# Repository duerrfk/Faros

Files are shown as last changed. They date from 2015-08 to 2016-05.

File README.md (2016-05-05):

Faros is a Bluetooth Low Energy (BLE) beacon supporting Google's open beacon 
format Eddystone [1]. As hardware platform, Faros uses Arduino and the nRF8001 
BLE chip by Nordic Semiconductors [2].

The main features are:

* Full support for all Eddystone frame types (UID, URL, TLM)
* Energy efficiency allowing for runtimes of several years
* Using popular and powerful hardware platforms: Arduino and nRF8001 BLE chip
* Simplicity of hardware: easy to build using a commodity Arduino or our
  Faros board together with the BLE module MOD-nRF8001 from Olimex [3]
* Liberal licensing: Apache License 2.0 for software, CERN Open Hardware 
  Licence v1.2 for hardware 

The following images show a self-etched Faros board and a Faros board
manufactured by a PCB manufacturer.

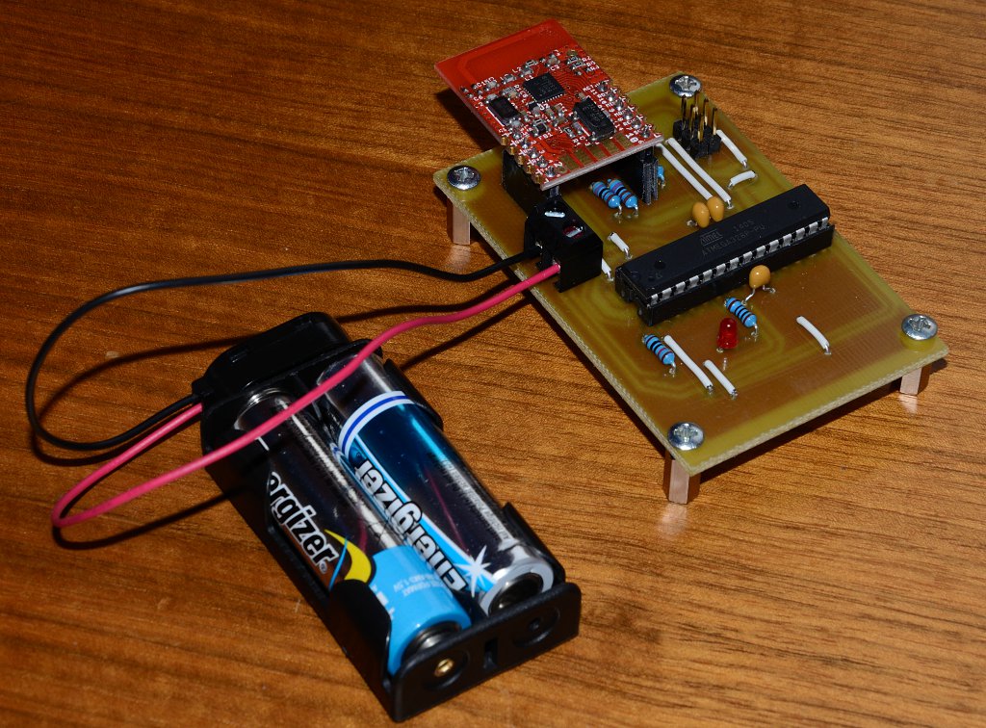
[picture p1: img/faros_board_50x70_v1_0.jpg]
Self-etched Faros board


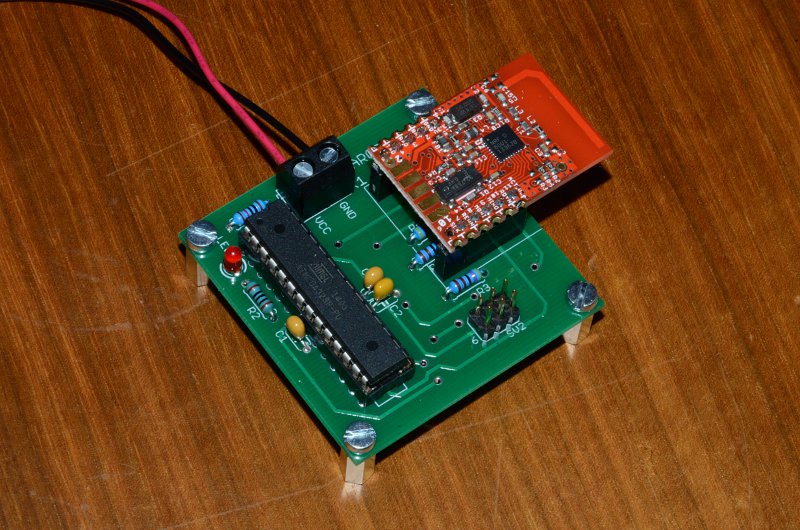
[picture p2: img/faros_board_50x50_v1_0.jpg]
Faros PCB manufactured by Seeed Studio


This project includes:

* Source code for Arduino
* Faros board schematics and board layouts

# Source Code

## Prerequisites

To compile the code, you need the Arduino IDE (tested with version 1.6.5).

Moreover, you need the Arduino BLE SDK from Nordic Semiconductors available 
from GitHub:

https://github.com/NordicSemiconductor/ble-sdk-arduino

1. Download SDK: `git clone https://github.com/NordicSemiconductor/ble-sdk-arduino.git`
2. Start the Arduino IDE (tested with v1.6.5)
3. Import the library: select `Sketch/Import library/Add` library and 
   then choose folder `libraries/BLE` from the downloaded SDK.
4. Check the availability of the library. There should be an entry `BLE`
   in menu `Sketch/Import library`.

The BLE services of nRF8001 are configured by the freely available nRFgo 
Studio tool (Windows application) [5]. This tool generates a file 
(`services.h`), which is also included in the repository. Thus, you  
only need to install this tool if you want to modify the BLE service 
description for some reason. The data of Eddystone frames is defined in the 
source code.

You also need the BLE module MOD-nRF8001 from Olimex [3]. Earlier versions 
of this module used the "C" revision of the nRF8001, which does not support
broadcasting data! So you need a module with the "D" revision of the nRF8001.
According to Olimex, all modules sold now have the "D" revision of the
nRF8001.

Since the nRF8001 module is specified for a voltage range of 1.9 V - 3.6 V, 
you should use an Arduino with suitable voltage levels. For instance, 
Arduino UNO uses 5 V, so you would have to shift levels when connecting to 
nRF8001. We tested with a 3.3 V Arduino Pro Micro and the Faros board
whose design is also included in this repository.
 
## Adapting the Source Code

If you use the Faros board or Arduino Pro Micro, you can simply
set the following definitions at the beginning of the sketch.

For the Faros board:

    #define HARDWARE_ATMEGA328P_1MHz

For Arduino Pro Micro:

    #define HARDWARE_ATMEGA32U4_8MHz

For those who are interested in the technical details: The Arduino communicates
with the nRF8001 through SPI. Beyond the standard SPI pins (MISO, MOSI, SCK, 
SS), the nRF8001 uses another select pin (called RDYN) to signal that the 
nRF8001 has events to be sent to the Arduino. Moreover, the reset pin (RST) of 
the nRF8001 has to be connected. Thus, we need 6 pins to connect the Arduino 
to the nRF8001:

1. MISO
2. MOSI
3. SCK
4. REQN/SS
5. RDYN
7. RST

For the standard SPI pins, select the usual pins depending on your Arduino.
RDYN should be assigned to a pin with a hardware interrupt. We use this 
interrupt to wake up the Arduino from power-down mode when the nRF8001 wants
to send an event to the Arduino.

For the Arduino Pro Micro, we used the following pins according to the
Arduino numbering scheme:

* MISO = 14
* MOSI = 16
* SCK = 15
* REQN/SS = 7
* RDYN = 3 -> INT0
* RST = 4

For the Faros board based on ATmega328P, we used the following pins (Arduino 
numbering scheme; ATmega names are given in brackets):

* MISO = 12 (PB4)
* MOSI = 11 (PB3)
* SCK = 13 (PB5)
* REQN/SS = 10 (PB2)
* RDYN = 2 (PD2) -> INT0
* RST = 3 (PD3)

Moreover, nRF8001 supports a maximum SPI clock frequency of 3 MHz. To adjust the
SPI clock frequency, set the definition SPI_CLOCK_DIV according to your 
platform. For instance, the Arduino Pro Micro is running at 8 MHz, so we need 
to divide it by 4 (SPI_CLOCK_DIV4) to get 2 MHz. The Faros board uses an 
ATmega328P at 1 MHz, so theoretically we could divide by 1. However, the 
smallest divider available for ATmega is 2 (SPI_CLOCK_DIV2), so we will run at 
500 kHz SPI clock.

Finally, you need to set your specific data to be broadcasted by the beacon.
Eddystone supports the following data:

* UID frames:
    * beacon ID consisting of namespace id and instance id
    * TX power level
* URL frame: 
    * short URL 
    * TX power level
* TLM frame: 
    * battery level
    * temperature
    * uptime
    * number of broadcasted frames since boot

You need to set the data for UID and URL frames through variables at the 
beginning of the sketch. The data for TLD frames is detected automatically 
(nRF8001 features a temperature sensor and voltage sensor).

Moreover, you can select whether you want to send UID and/or URL frames 
and/or TLM frames by setting the variables `is_enabled_uid`, `is_enabled_url`, 
and `is_enabled_tlm`, respectively. The beacon will cycle through all 
enabled frames, so it can send UID frames, URL frames, and TLM frames 
(sequentially).

# Hardware: The Faros Board

If you just want to experiment, you can simply use a commodity Arduino 
running at 3.3 V like the Arduino Pro Micro. Just directly connect the pins
of the Arduino Pro Micro and the BLE module like this:

* MISO = 14
* MOSI = 16
* SCK = 15
* REQN/SS = 7
* RDYN = 3 -> INT0
* RST = 4

However, if you want to deploy beacons in the field, two requirements become 
essential:

* Energy efficiency: the beacon must run from battery for several years 
* Cost: if you want to deploy many beacons, a commodity Arduino board
  is too expensive

The Faros board tries to fulfill these requirements plus one more: keep
things as simple as possible so virtually everyone can build a Faros
beacon.

The Faros board uses an ATmega328P together with the BLE module MOD-nRF8001 
from Olimex [3] based on the nRF8001 chip from Nordic Semiconductors. We 
selected the nRF8001 for several reasons:

* Easy to connect to Arduino through SPI
* Open Arduino SDK [4]
* Includes temperature sensor (required for TLM frames)
* Includes voltage sensor (required for TLM frames)

The BLE module MOD-nRF8001 from Olimex provides a ready-to-use solution to use
the nRF8001 together with the Arduino.

The Faros board is kept as simple as possible (through-hole design, no SMD 
components). It comes in two variants: (1) a single-sided 50 mm x 70 mm layout 
that is well-suited for self-etching (a PDF of the layout can be found in 
folder `pcb`); (2) a double-sided 50 mm x 50 mm layout that can be sent to a 
PCB manufacturer (the Gerber files can be found in folder `gerber`). For both 
variants, the ATmega is programmed using ISP, so no USB is required which 
again saves cost and energy. Moreover, we use the ATmega's internal RC 
oscillator, so no external crystal is required. 

Here is the bill of material for the Faros board:

* C1, C2, C3: 100 nF (ceramic capacitor, X7R, 5.08 pitch)
* LED1: 3 mm
* R1: 10 k Ohm
* R2: 100 Ohm
* R3, R4, R5: 4.7 k Ohm
* IC1: ATmega328P-PU
* MOD1: Olimex MOD-nRF8001
* SV1: 3x2 pin header (2.54 pitch)
* X1: screw terminal (5.08 pitch)

## Programming the Faros Board

The Faros board is programmed via ISP. The 6 pin ISP6 connector has the usual 
layout:

    MISO <-- 1 2 --> VCC
     SCK <-- 3 4 --> MOSI
     RST <-- 5 6 --> GND

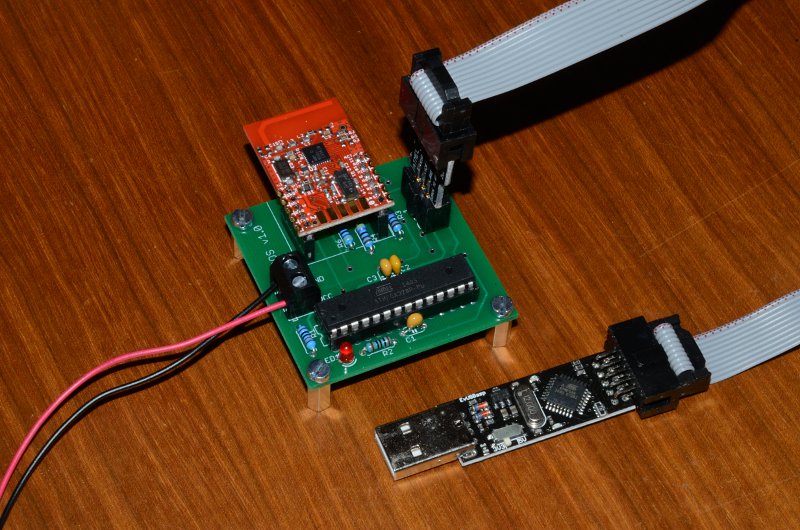
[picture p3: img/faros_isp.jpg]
Faros board connected to ISP


You can leave the BLE module connected while programming the ATmega (the 
4.7 k resistors shield the SPI pins of the nRF8001 during programming). However,
you should use a 3.3 V programmer since the maximum voltage of the nRF8001
is 3.6 V.

To preprare the ATmega328P, program the following fuses (note that "0" means 
that the fuse is programmed):

* CKSEL = 0010: use internal 8 MHz RC oscillator
* CKDIV8 = 0: 1 MHz system clock (dividing the 8 MHz internal clock by 8)
* SPIEN = 0: enable serial programming
* BODLEVEL = 110: brown-out detection set to 1.8 V
* SUT = 00: lowest possible startup time (6 CK from power-down; since we use
  BOD, we do not need additional waiting time for the power source to come up)
    
Using avrdude, the command looks like this (note: under Linux you might need
to execute this command as root depending on your programmer):

    $> avrdude -c usbasp -p m328p -U lfuse:w:0x42:m -U hfuse:w:0xd9:m -U efuse:w:0x06:m

Then, we compile and write the program to the ATmega. Before compiling the 
program, make sure you have adapted the pins (see above), SPI clock divider 
(see above), and to generate code for an ATmega at 1 MHz. In the repository, 
you will find a suitable board definition for the Arduino IDE (see folder 
`board_definition`). Copy the directory `faros-atmega` into the folder 
`hardware` in your Arduino sketchbook. Then you should find and select the 
board  called `Faros ATMega 328P @ 1 MHz` under the menu item `Tools/Board`. 

Compiling generates a hex file that we need to program the ATmega. This hex 
file is a little bit hidden in the temporary build directory of the Arduino
IDE. If you use Linux  and Arduino IDE 1.6, have a look at the `/tmp` 
directory. After hitting the  compile button in the Arduino IDE, search for the
latest hex file called  `faros.cpp.hex` in a temporary directory named 
`/tmp/build...`. If you have found the hex file, you can write it using avrdude
(again, you might need root right):

    $> avrdude -p m328p -c usbasp -v -U flash:w:faros.cpp.hex
 
## Saving Energy

The basic method to save energy is to minimize the duty cycle. Therefore,
we put the ATmega into power-down mode (deepest power-saving mode) as long as
possible, and only wake it up, when some work has to be done. This can either
be an event from the nRF8001 module , which triggers a hardware interrupt on
the RDYN pin. Or it can be a timer event from the watch dog timer (which
keeps running in power-down mode in contrast to the other timers). By switching
of the ADC and disabling brown-out detecting while sleeping (only possible
with the ATmega328P, not with the ATmega328), the ATmega328P only consumes 
a few uA (actually, the "P" in 328P means "pico-power"). 

Another important design choice is the type of battery. The nRF8001 
can run down to 1.9 V; the ATmega down to 1.8 V at frequencies <= 4 MHz. The 
maximum voltage for the nRF8001 is 3.6 V. Thus, one good option is to use two 
AA or AAA size alkaline batteries. They are cheap. They provide > 1800 mAh, 
which should suffice for several years of runtime. They are discharged at about 
1.0 V (then the voltage drops rapidly), which fits nicely our desired voltage 
range of 1.9 - 3.0 V. And at runtimes of several years, no re-charging is
required (you rather replace the device than changing the batteries). Of 
course, you can also try out other options like coin cells (e.g., one 
CR 2450 @ 3.0 V, 560 mAh), or one battery (1.5 V) plus a step-up converter 
(which wastes maybe more than 20 % energy for conversion and is probably more
expensive than a second AA or AAA battery).

The board also has a 3 mm low-current LED, which can be switched on by digital 
pin 4 of the Arduino. With a resistor of 100 Ohm, it draws 10 mA at 3 V, which 
is a lot if we target runtimes of several years! So if you aim at maximum 
battery lifetime, only send short pulses in long intervals (e.g., one 100 ms 
pulse every 30 s amounts to about 33 uA average current), or even better: rely 
on TLM frames.

# Testing

In order to test that your beacon works, you need a client, e.g., a mobile
phone or tablet with BLE and an application that understands Eddystone
beacons. There are (at least) two nice apps for Android that show all the
details of the three types of Eddystone frames:

* nRFMaster Control Panel by Nordic Semiconductors [6]
* Eddystone Validator by Google (requires Android 5 aka. Lollipop) [7]

Faros is cycling through all frame types (if you have enabled all of them)
and switches to a new frame type every second. So after about 3 seconds you 
should see the data of all three frame types (most interesting is maybe
the TLM type since its data changes dynamically).

# Licensing

Faros uses two licenses for open hardware and software, respectively:

* The software (source code) is licensed under the Apache License 2.0 [8]
* The hardware (schematic diagrams, circuit board layouts, hardware
  documentation) is licensed under the CERN Open Hardware Licence v1.2 [9]

Both licenses are also included in the repository.

# References

* [1] https://developers.google.com/beacons/
* [2] https://www.nordicsemi.com/eng/Products/Bluetooth-Smart-Bluetooth-low-energy/nRF8001 
* [3] https://www.olimex.com/Products/Modules/RF/MOD-nRF8001/
* [4] https://github.com/NordicSemiconductor/ble-sdk-arduino
* [5] https://www.nordicsemi.com/chi/node_176/2.4GHz-RF/nRFgo-Studio
* [6] https://www.nordicsemi.com/eng/Products/nRFready-Demo-Apps/nRF-Master-Control-Panel-application
* [7] https://github.com/google/eddystone
* [8] http://www.apache.org/licenses/LICENSE-2.0
* [9] http://www.ohwr.org/attachments/2388/cern_ohl_v_1_2.txt

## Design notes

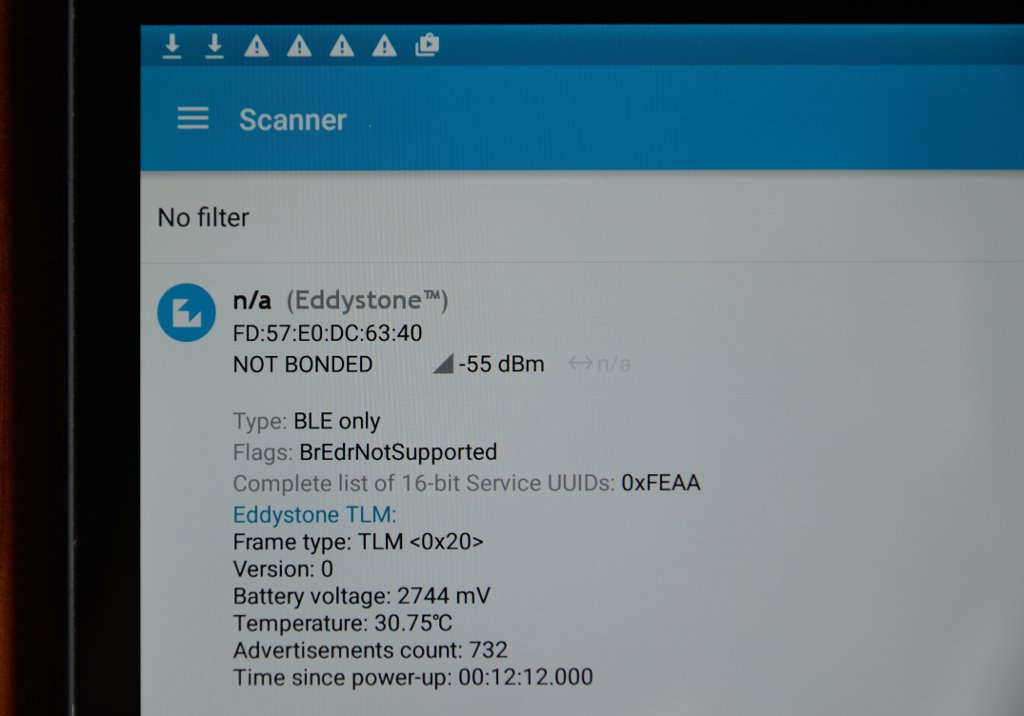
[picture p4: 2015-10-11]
img/nrfmaster03.jpg

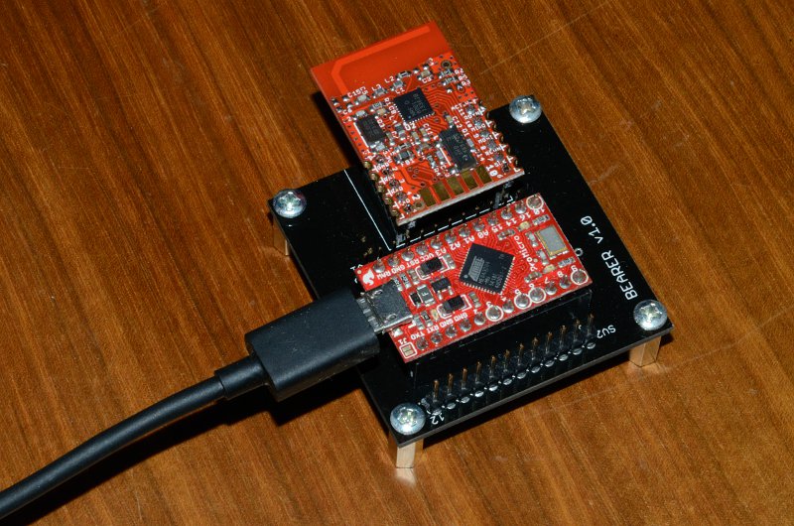
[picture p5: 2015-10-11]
img/faros_arduinopromicro.jpg

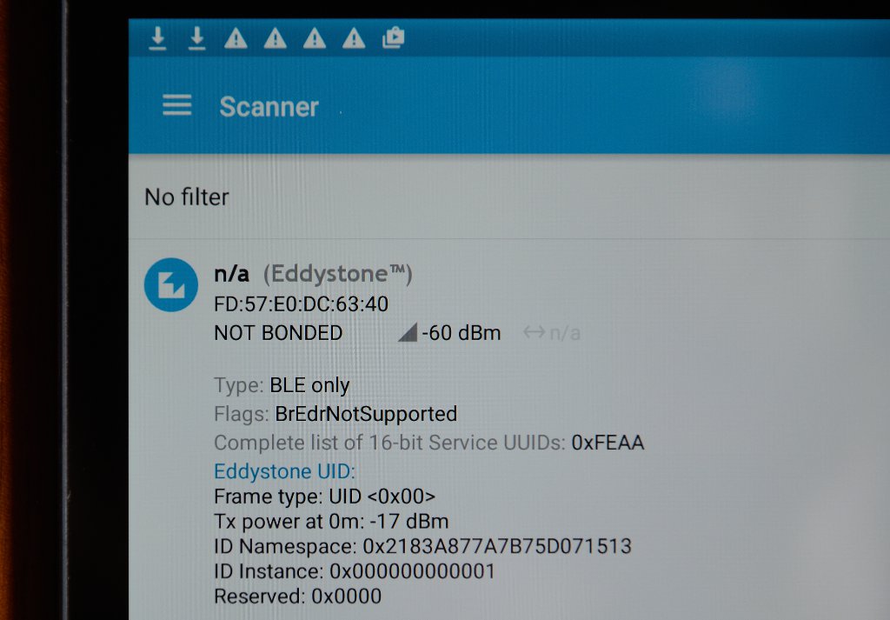
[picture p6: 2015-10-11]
img/nrfmaster01.jpg

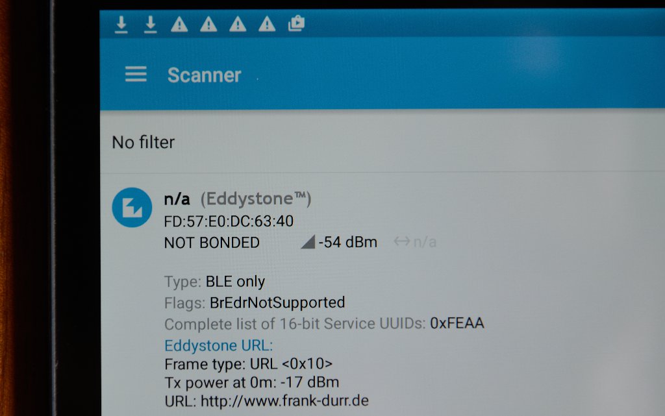
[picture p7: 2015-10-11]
img/nrfmaster02.jpg

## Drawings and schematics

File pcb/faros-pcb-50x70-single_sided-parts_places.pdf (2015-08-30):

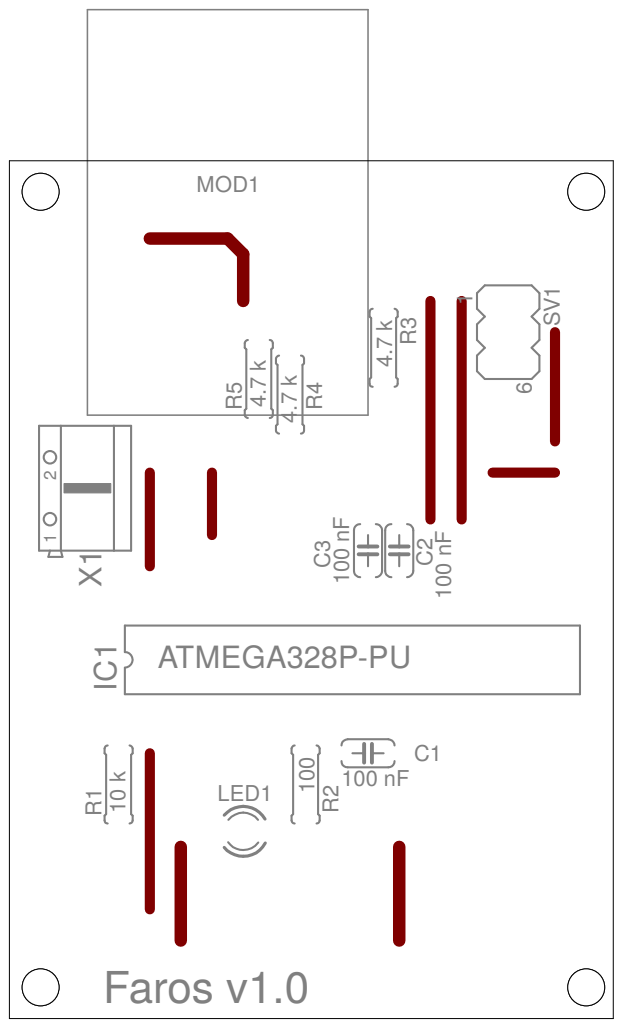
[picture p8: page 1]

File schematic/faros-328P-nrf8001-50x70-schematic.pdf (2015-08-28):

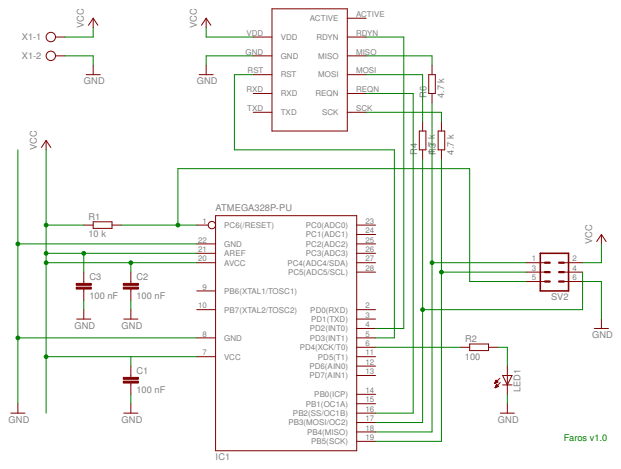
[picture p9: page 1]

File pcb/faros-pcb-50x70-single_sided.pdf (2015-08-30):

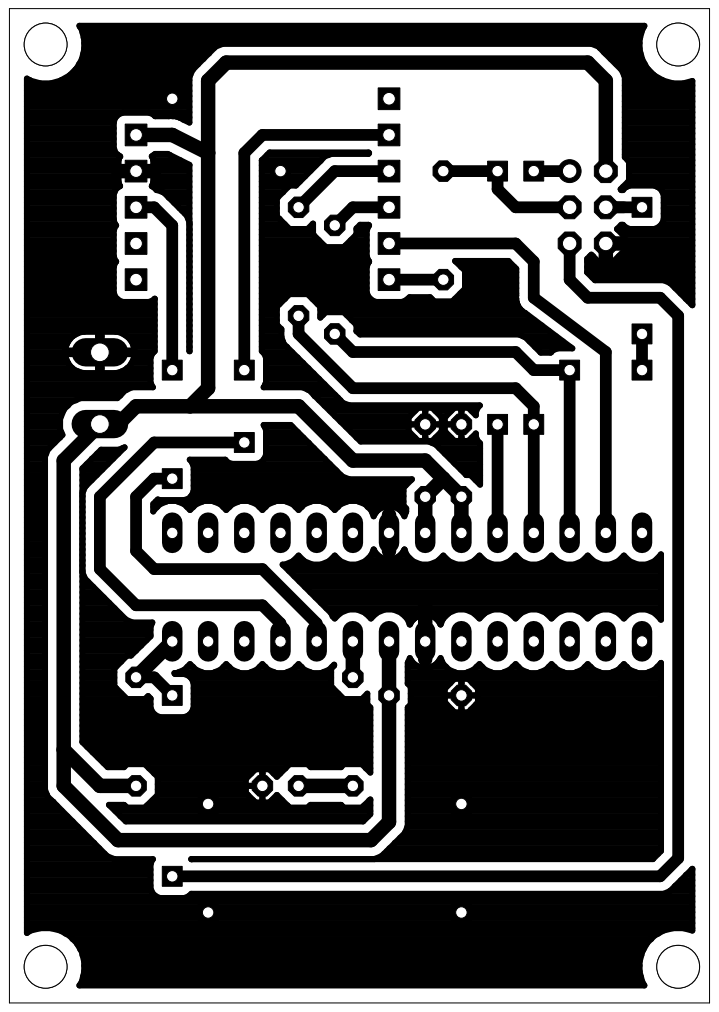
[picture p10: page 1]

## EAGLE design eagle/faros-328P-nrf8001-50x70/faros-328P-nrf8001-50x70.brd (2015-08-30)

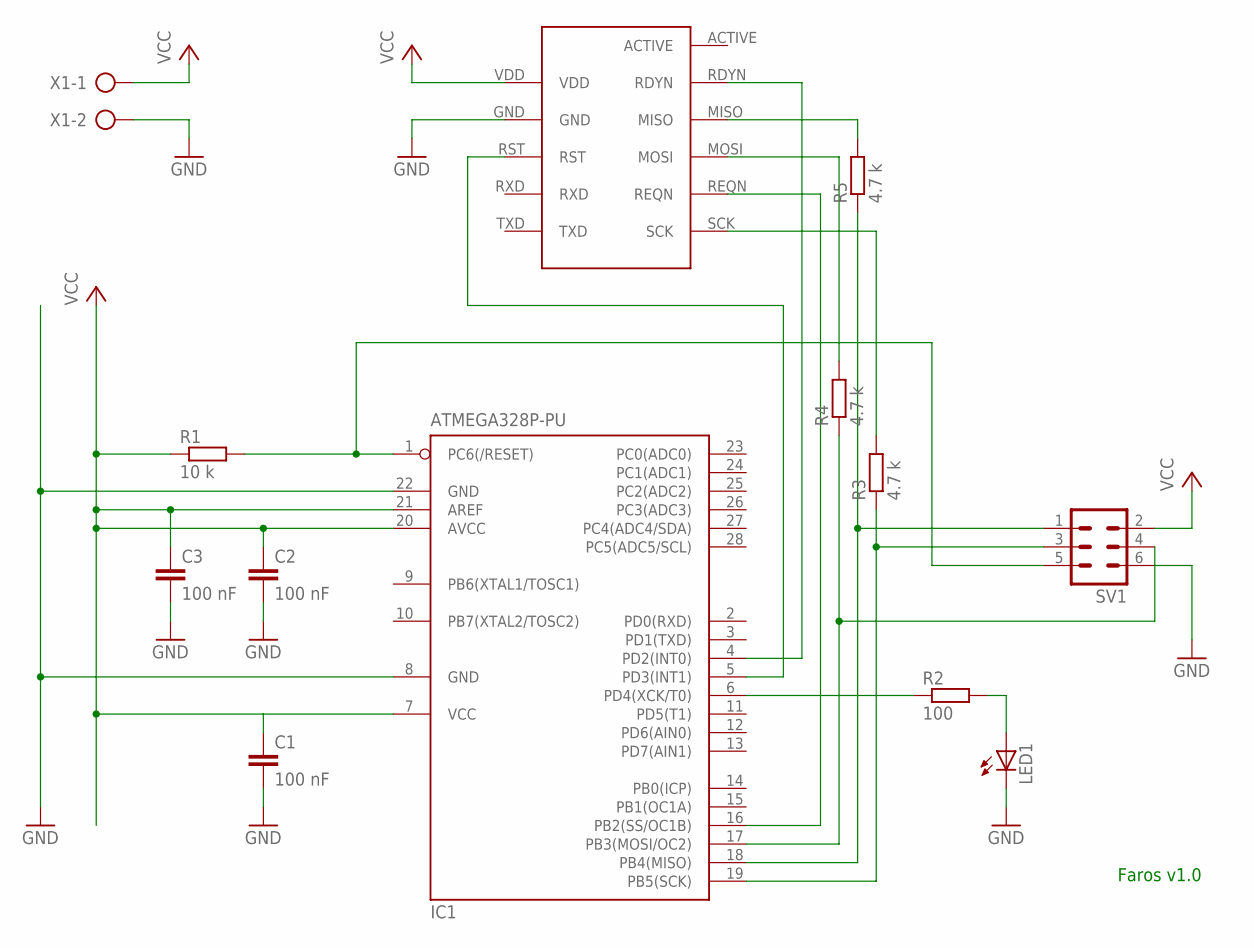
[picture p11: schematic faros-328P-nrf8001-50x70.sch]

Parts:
C1, C2, C3: 100 nF; C050-024X044
IC1: ATMEGA328P-PU; DIL28-3
LED1: LED3MM
MOD1: MOD-NRF8001MOD-NRF8001; MOD-NRF8001
R1: 10 k; 0207/7
R2: 100; 0207/7
R3, R4, R5: 4.7 k; 0207/7
SV1: MA03-2
X1: AK500/2

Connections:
GND: C1.2, C2.2, C3.2, IC1.8 (GND), IC1.22 (GND), LED1.K (C), MOD1.GND, SV1.6, X1.2
unnamed: IC1.4 (PD2(INT0)), MOD1.RDYN
unnamed: IC1.19 (PB5(SCK)), R3.1, SV1.3
unnamed: IC1.1 (PC6(/RESET)), R1.2, SV1.5
unnamed: MOD1.MOSI, R4.2
unnamed: MOD1.MISO, R5.2
unnamed: IC1.5 (PD3(INT1)), MOD1.RST
unnamed: LED1.A, R2.2
unnamed: IC1.6 (PD4(XCK/T0)), R2.1
unnamed: MOD1.SCK, R3.2
unnamed: IC1.16 (PB2(SS/OC1B)), MOD1.REQN
unnamed: IC1.18 (PB4(MISO)), R5.1, SV1.1
unnamed: IC1.17 (PB3(MOSI/OC2)), R4.1, SV1.4
VCC: C1.1, C2.1, C3.1, IC1.7 (VCC), IC1.20 (AVCC), IC1.21 (AREF), MOD1.VDD, R1.1, SV1.2, X1.1

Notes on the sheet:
Faros v1.0

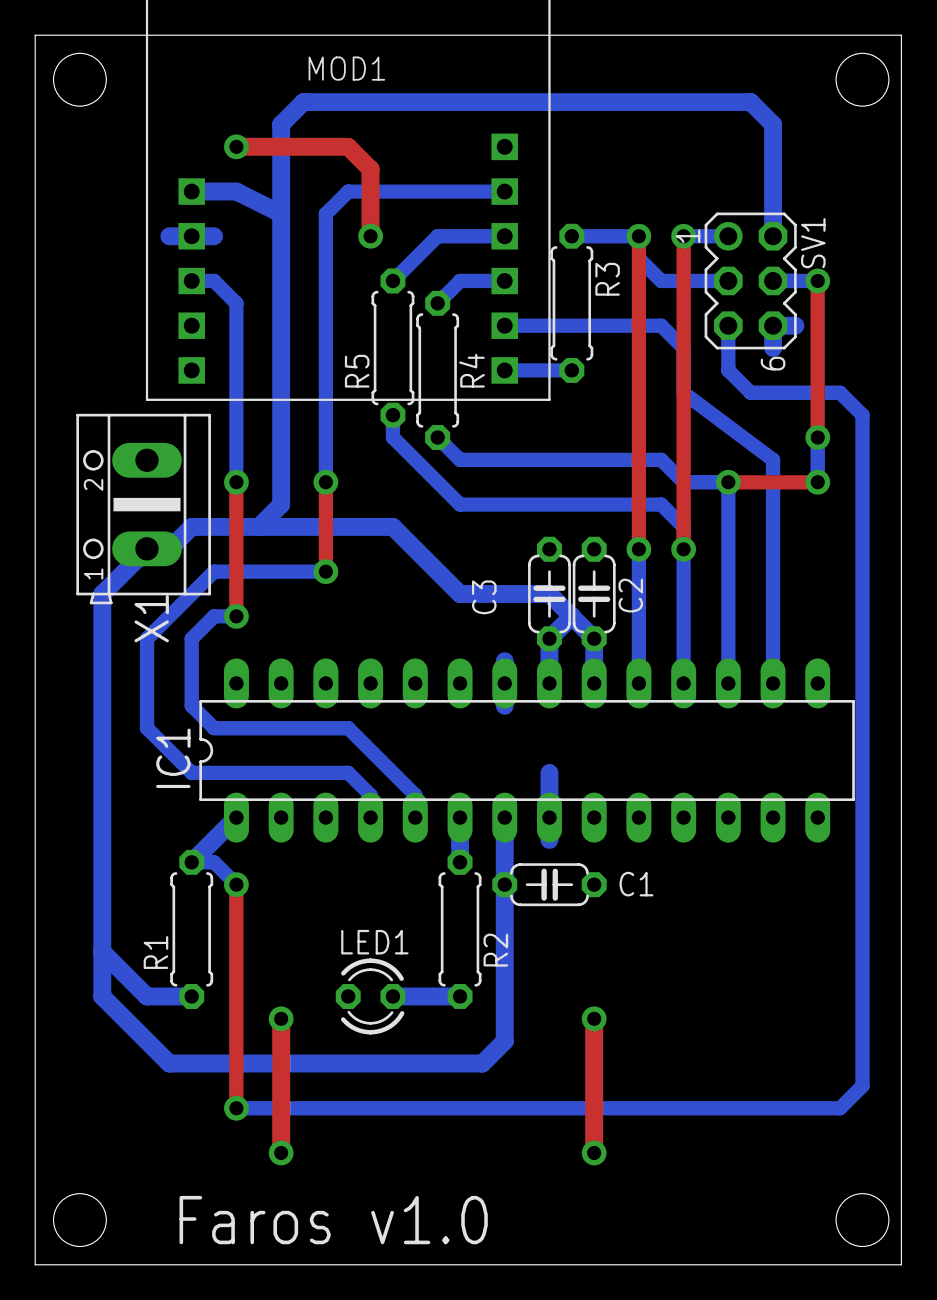
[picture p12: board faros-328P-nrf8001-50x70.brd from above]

Board: 2 copper layers, 49.2 x 69.8 mm, 13 parts (0 on the bottom side), 14 nets.

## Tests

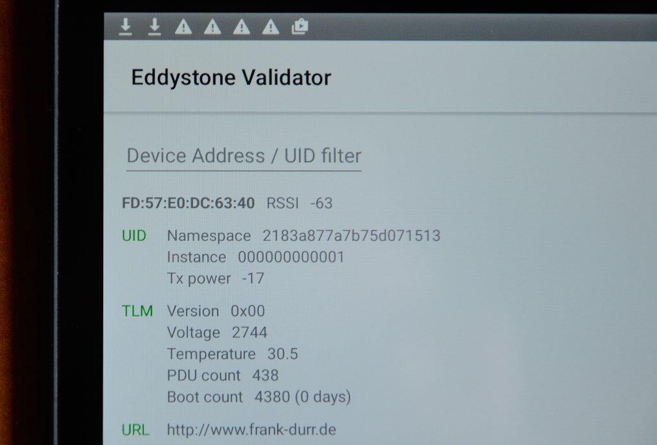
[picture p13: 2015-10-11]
img/validator.jpg

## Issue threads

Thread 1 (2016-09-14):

Will this work with nrf24l01?

Milap7, 2016-09-14:

duerrfk, 2016-09-14:
No, you need a board with [nRF8001](https://www.nordicsemi.com/eng/Products/Bluetooth-low-energy/nRF8001), such as the [MOD-nRF8001](https://www.olimex.com/Products/Modules/RF/MOD-nRF8001/) (the provided PCB layout is for this board) or [Bluefruit LE](https://www.adafruit.com/product/1697).

Closed 2016-09-14.

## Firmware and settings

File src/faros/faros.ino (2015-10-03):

/**
 * This file is part of Faros.
 * 
 * Copyright 2015 Frank Duerr
 *
 * Licensed under the Apache License, Version 2.0 (the "License");
 * you may not use this file except in compliance with the License.
 * You may obtain a copy of the License at
 * 
 * http://www.apache.org/licenses/LICENSE-2.0
 * 
 * Unless required by applicable law or agreed to in writing, software
 * distributed under the License is distributed on an "AS IS" BASIS,
 * WITHOUT WARRANTIES OR CONDITIONS OF ANY KIND, either express or implied.
 * See the License for the specific language governing permissions and
 * limitations under the License.
 */
 
// Need to include EEPROM.h here although it is not reference from this file
// (at least Arduino 1.5.8 IDE fails to include it automatically). 
#include <EEPROM.h>
#include <SPI.h>
#include <avr/wdt.h>
#include <avr/sleep.h>
#include <lib_aci.h>
#include <aci_setup.h>
#include "services.h"
#include "url_schemes.h"
#include "commands.h"

//// Define your hardware platform to set pin mappings, etc. 
// The following definition is suitable for the Faros board. 
//#define HARDWARE_ATMEGA328P_1MHz
// The following definition is suitable for Arduino Pro Micro.
#define HARDWARE_ATMEGA32U4_8MHz

// Putting the MCU into power-down mode is essential to save 
// energy and to achieve runtimes of several years. However, 
// be careful if you use an Arduino flashed via serial port
// like Arduino Pro Micro. If the serial port is not 
// discovered by your PC until the device falls asleep, you 
// might not be able to flash it anymore, via serial port. 
// To recover, you have two options: 
//
// 1. Connect a cable between PIN_RDYN and GND of the Arduino. 
//    This will prevent the the activation of power-down 
//    mode since INT0 is constantly active (the device thinks,
//    that the nRF8001 wants to send events).
// 2. Flash via ISP
//
// Since the Faros board is flashed via ISP anyway, it is
// save to use this setting with the Faros board.
#ifdef HARDWARE_ATMEGA328P_1MHz
#define DO_SLEEP
#endif

// Disabling brown-out detecting while sleeping saves about 25 uA.
// Not all MCUs support this. ATmega328P used by the Faros board 
// does. ATmega32U4 used by Arduino Pro Micro doesn't.
#ifdef HARDWARE_ATMEGA328P_1MHz
#define DISABLE_BOD_WHILE_SLEEPING
#endif

// 8.8 fixed point arithmetic
#define FIXED_8_8_FBITS 8
#define FIXED_8_8_ONE (1<<FIXED_8_8_FBITS)
#define FIXED_8_8_FROM_FLOAT(x) ((int16_t) ((x)*FIXED_8_8_ONE))

//// Arduino pins connected to nRF8001.
#ifdef HARDWARE_ATMEGA32U4_8MHz
// The following values are valid for Arduino Pro Micro. 
#define PIN_MOSI 16
#define PIN_MISO 14
#define PIN_SCK 15
// nRF8001 uses two "slave select" pins, one from Arduino (master) to nRF8001
// (slave) called REQN, and one from slave to master called RDYN for signaling 
// events from nRF8001 to Arduino. For RDYN select a pin with attached 
// hardware interrupt to enable wake-up from sleep mode. 
#define PIN_REQN 7
#define PIN_RDYN 3  
#define PIN_RST 4

// We use this interrupt to react to RDYN events. nRF8001 pulls
// RDYN low, when it has some data to send to the MCU.
// pin 3 = RDYN is linked to INT0 on Arduino Pro Micro.
#define RDYN_INTR_NO 0

// nRF8001 supports max. 3 MHz SPI clock frequency.
// Arduino Pro Micro runs at 8 MHz. By dividing by 4, we
// set the SPI clock frequency to 2 MHz.    
#define SPI_CLOCK_DIV SPI_CLOCK_DIV4
#endif

#ifdef HARDWARE_ATMEGA328P_1MHz
// The following values are valid for the Faros board. 
#define PIN_MOSI 11
#define PIN_MISO 12
#define PIN_SCK 13
// nRF8001 uses two "slave select" pins, one from Arduino (master) to nRF8001
// (slave) called REQN, and one from slave to master called RDYN for signaling 
// events from nRF8001 to Arduino. For RDYN select a pin with attached 
// hardware interrupt to enable wake-up from sleep mode. 
#define PIN_REQN 10
#define PIN_RDYN 2  
#define PIN_RST 3

// We use this interrupt to react to RDYN events. nRF8001 pulls
// RDYN low, when it has some data to send to the MCU.
// pin 2 = RDYN is linked to INT0 on the Faros board.
#define RDYN_INTR_NO 0

// nRF8001 supports max. 3 MHz SPI clock frequency.
// The Faros board runs at 1 MHz. Two is the smallest clock
// divider that we can set:    
#define SPI_CLOCK_DIV SPI_CLOCK_DIV2
#endif

// Advertisement interval in 0.625 ms, min 0x0020 (20 ms), max 0x4000 (10.240 s). 
// 1600 -> 1 s
#define ADV_INTERVAL 1600

// Maximum sizes of the different Eddystone frames 
#define EDDYSTONE_UID_DATA_SIZE 20
#define EDDYSTONE_URL_DATA_SIZE 20
#define EDDYSTONE_TLM_DATA_SIZE 14

//// nRF8001 data structures
#ifdef SERVICES_PIPE_TYPE_MAPPING_CONTENT
    services_pipe_type_mapping_t services_pipe_type_mapping[NUMBER_OF_PIPES] = SERVICES_PIPE_TYPE_MAPPING_CONTENT;
#else
    #define NUMBER_OF_PIPES 0
    services_pipe_type_mapping_t *services_pipe_type_mapping = NULL;
#endif

// Store the setup for the nRF8001 in the flash of the AVR (PROGMEM) to save on RAM
const hal_aci_data_t setup_msgs[NB_SETUP_MESSAGES] PROGMEM = SETUP_MESSAGES_CONTENT;

// Selection of Eddystone frame types that should be sent
const boolean is_enabled_uid = true;
const boolean is_enabled_url = true;
const boolean is_enabled_tlm = true;

//// Definition of data for the different Eddystone frame types.
// Note that multi-byte Eddystone data is in Big-Endian format.
// Frame type ids
const uint8_t eddystone_frame_type_uid = 0x00;
const uint8_t eddystone_frame_type_url = 0x10;
const uint8_t eddystone_frame_type_tlm = 0x20;

// 10 byte namespace id. Google suggests different methods to create this:
// - Truncated hash: first 10 bytes of your SHA1 hash of your FQDN.
// - Elided Version 4 UUID: version 4 UUID with bytes 5 - 10 (inclusive) removed 
const uint8_t eddystone_namespace_id[] = {0x21, 0x83, 0xa8, 0x77, 0xa7, 0xb7, 0x5d, 0x07, 0x15, 0x13};
// 6 byte instance id (any scheme you like).
const uint8_t eddystone_instance_id[] = {0x00, 0x00, 0x00, 0x00, 0x00, 0x01};
// TX power in dBm, calibrated at 0 m distance.
// Range: -100 dBm to +20 dBm; resolution: 1 dBm.
// Can be found out empirically by measuring the signal strength at 1 m.
// distance and adding 41 dBm.
const int8_t eddystone_txpwr = -17;
// Scheme of the encoded URL.
const url_schemes eddystone_url_scheme = http_www_dot;
// Encoded URL (max. 17 bytes)
// The following bytes expand to a sequence of characters:
// 0x00  .com/
// 0x01  .org/
// 0x02  .edu/
// 0x03  .net/
// 0x04  .info/
// 0x05  .biz/
// 0x06  .gov/
// 0x07  .com
// 0x08  .org
// 0x09  .edu
// 0x0a  .net
// 0x0b  .info
// 0x0c  .biz
// 0x0d  .gov
// 14..32  0x0e..0x20  Reserved for Future Use
// 127..255  0x7F..0xFF  Reserved for Future Use
// The following example encodes the URL frank-duerr.de
// ("http://www." is added by the schema definition)
const uint8_t eddystone_enc_url[] = {0x66, 0x72, 0x61, 0x6e, 0x6b, 0x2d, 0x64, 0x75, 0x72, 0x72, 0x2e, 0x64, 0x65};
const unsigned int eddystone_enc_url_size = sizeof(eddystone_enc_url);
// TLM version
const uint8_t eddystone_tlm_version = 0x00;

// Complete Eddystone UID frame:
// - 1 byte frame type (0x00 for UID frame)
// - 1 byte TX power
// - 10 byte namespace id
// - 6 byte instance id
// - 2 bytes reserved (must be set to 0x00 0x00)
uint8_t eddystone_uid_data[EDDYSTONE_UID_DATA_SIZE];
unsigned int eddystone_uid_data_size;
 
// Complete Eddystone URL frame:
// - 1 byte frame type (0x10 for UID frame)
// - 1 byte TX power
// - 1 byte URL scheme
// - 0-17 bytes encoded URL
uint8_t eddystone_url_data[EDDYSTONE_URL_DATA_SIZE];
unsigned int eddystone_url_data_size;

// Complete Eddystone TLM frame:
// - 1 byte frame type (0x20 for TLM frame)
// - 1 byte TLM version (currently 0x00)
// - 2 byte battery level in millivolt. 
// - 2 byte temperature (degree Celsius; signed 8.8 fixed point notation)
// - 4 bytes adv. PDU count (total count of advertisement frames of 
//   all types emitted by the beacon since (re-)boot)
// - 4 bytes time since (re-)boot (0.1 sec resolution)
uint8_t eddystone_tlm_data[EDDYSTONE_TLM_DATA_SIZE];
unsigned int eddystone_tlm_data_size;

// Temperature [degree Celsius]
float temperature = 12.34;
// Battery level [volt]
float voltage = 1.23;
// Total number of advertisement frames sent since re-boot
uint32_t adv_pdu_cnt = 0;
// Uptime in tens of seconds
uint32_t uptime = 0;

struct aci_state_t aci_state;
hal_aci_evt_t  aci_data;
hal_aci_data_t aci_cmd;

volatile boolean ble_ready = false;
volatile boolean timer_fired = false;
boolean is_broadcasting = false;

// Eddystone frame types are sent round robin. 
// Variable next_frame_type tells, which frame type to send next.
enum frame_types {uid, url, tlm};
enum frame_types next_frame_type;

// nRF8001 can only process one system command at a time.
// After sending a request, we need to wait for the response
// before sending the next command. In order to simplify implementation,
// we queue pending commands in a command queue. Whenever a response
// is received, the next command is taken out of the queue and sent
// to nRF8001. The command queue is implemented as a ring buffer.
#define CMD_QUEUE_SIZE 16
#define CMD_QUEUE_SIZE_MOD_MASK 0x0f 
enum commands cmd_queue[CMD_QUEUE_SIZE];
unsigned int cmd_queue_head = 0;
unsigned int cmd_queue_tail = 0;
unsigned int cmd_queue_free = CMD_QUEUE_SIZE;
boolean cmd_queue_pending = false;

/**
 * Called after a fatal error happened. 
 */
void die()
{  
    // Enable watchdog system reset mode to reboot system with next
    // watch dog event. 
    //WDTCSR |= _BV(WDE);
    
    // Go into endless loop. User will notice error through TLM frames
    // (either missing or counters don't increase anymore).
    while (true);
}

/**
 * Enqueue a command into the command queue. 
 * 
 * @param command the command to be enqueued
 * 
 * @returns true if the command fits into the queue; false if
 *          there is no space in the queue anymore.
 */
boolean cmd_queue_enqueue(enum commands command)
{
    if (cmd_queue_free == 0)
        return false;

    cmd_queue[cmd_queue_head] = command;
    cmd_queue_head++;
    cmd_queue_head &= CMD_QUEUE_SIZE_MOD_MASK;
    cmd_queue_free--;
    
    // Try to send command
    cmd_queue_send_cmd();

    return true;
}

/**
 * If no other command is pending and there is at least
 * one queued command, send next command to nRF8001.
 */
void cmd_queue_send_cmd() 
{
    // Cannot send a command if either a command is pending 
    // or queue is empty
    if (cmd_queue_pending || cmd_queue_free == CMD_QUEUE_SIZE)
        return;
        
    enum commands cmd = cmd_queue[cmd_queue_tail];
    switch (cmd) {
    case get_temperature :
        lib_aci_get_temperature();
        break;
    case get_battery_level :
        lib_aci_get_battery_level();
        break;
    case send_uid_frame :
        lib_aci_set_local_data(&aci_state, 
            PIPE_EDDYSTONE_EDDYSTONEDATA_BROADCAST,
            eddystone_uid_data, EDDYSTONE_UID_DATA_SIZE);
        break;
    case send_url_frame :
        lib_aci_set_local_data(&aci_state, 
            PIPE_EDDYSTONE_EDDYSTONEDATA_BROADCAST,
            eddystone_url_data, eddystone_url_data_size);
        break;
    case send_tlm_frame :
        eddystone_tlm_data_size = setup_eddystone_TLM_frame(eddystone_tlm_data, 
            eddystone_tlm_version, voltage, temperature, adv_pdu_cnt, uptime);
        lib_aci_set_local_data(&aci_state, 
            PIPE_EDDYSTONE_EDDYSTONEDATA_BROADCAST,
            eddystone_tlm_data, eddystone_tlm_data_size);
        break;
    case open_adv_pipe :
        lib_aci_open_adv_pipe(PIPE_EDDYSTONE_EDDYSTONEDATA_BROADCAST);
        break;
    case start_broadcasting :
        // Start advertising in non-connectable (broadcast) mode. 
        // First parameter defines the adv. timeout (how long to
        // advertise; 0 = forever). Second parameter is advertisement 
        // interval in milli-seconds.
        lib_aci_broadcast(0, ADV_INTERVAL);
        break;
    case send_hello :
        break;
    }
    
    cmd_queue_pending = true;
    
    cmd_queue_tail++;
    cmd_queue_tail &= CMD_QUEUE_SIZE_MOD_MASK;
    
    cmd_queue_free++;
}

/**
 * Received response for pending command.
 */
void cmd_queue_response_recvd()
{
    cmd_queue_pending = false;

    // Can send next enqueued command now (if any is available)
    cmd_queue_send_cmd();
}

/**
 * Setup an Eddystone TLM frame.
 * 
 * @param data array storing the frame data
 * @param version TLM version
 * @param battery_voltage voltage of the battery in Volts; 
 *        set to zero if not supported
 * @param beacon_temperature temperature of the beacon in degree Celcius
 *        set to -128 if not supported
 * @param adv_pdu_cnt total number of adv. frames sent since (re-)boot
 * @param uptime uptime in tens of seconds since (re-)boot
 * 
 * @return the size of the frame in bytes
 */
unsigned int setup_eddystone_TLM_frame(uint8_t data[EDDYSTONE_TLM_DATA_SIZE], 
    uint8_t version, float battery_voltage, float beacon_temperature, 
    uint32_t adv_pdu_cnt, uint32_t uptime)
{
    unsigned int offset = 0;
    
    data[offset] = eddystone_frame_type_tlm;
    offset++;
 
    data[offset] = version;
    offset++;

    // Convert battery level to millivolts
    uint16_t voltage = (uint16_t ) (battery_voltage*1000.0);
    // Store in Big Endian format
    data[offset] = (voltage>>8)&0xff;
    offset++;
    data[offset] = voltage&0xff;
    offset++;

    // Convert temperature to 8.8 fixed point format
    int16_t temperature = FIXED_8_8_FROM_FLOAT(beacon_temperature);
    // Store in Big Endian format
    data[offset] = (temperature>>8)&0xff;
    offset++;
    data[offset] = temperature&0xff;
    offset++;

    data[offset] = (adv_pdu_cnt>>24)&0xff;
    offset++;
    data[offset] = (adv_pdu_cnt>>16)&0xff;
    offset++;
    data[offset] = (adv_pdu_cnt>>8)&0xff;
    offset++;
    data[offset] = adv_pdu_cnt&0xff;
    offset++;

    data[offset] = (uptime>>24)&0xff;
    offset++;
    data[offset] = (uptime>>16)&0xff;
    offset++;
    data[offset] = (uptime>>8)&0xff;
    offset++;
    data[offset] = uptime&0xff;
    offset++;

    return offset;
}

/**
 * Setup an Eddystone URL frame.
 * 
 * @param data array storing the frame data
 * @param txpwr transmission power
 * @param scheme URL scheme
 * @param enc_url encoded URL 
 * @param enc_url_size length of the enc_url array
 * 
 * @return the size of the frame in bytes
 */
unsigned int setup_eddystone_URL_frame(uint8_t data[EDDYSTONE_URL_DATA_SIZE], 
    int8_t txpwr, enum url_schemes scheme, const uint8_t *enc_url, 
    unsigned int enc_url_size)
{
    unsigned int offset = 0;
    
    data[offset] = eddystone_frame_type_url;
    offset++;

    data[offset] = txpwr;
    offset++;

    uint8_t scheme_byte;
    switch (scheme) {
    case http_www_dot:
        scheme_byte = 0x00;
        break;
    case https_www_dot:
        scheme_byte = 0x01;
        break;
    case http: 
        scheme_byte = 0x02;
        break;
    case https:
        scheme_byte = 0x03;
        break;
    }
    data[offset] = scheme_byte;
    offset++;

    for (unsigned int i = 0; i < enc_url_size; i++) {
        data[offset] = enc_url[i];
        offset++;
    }

    return offset;
}

/**
 * Setup an Eddystone UID frame.
 * 
 * @param data array storing the frame data
 * @param txpwr transmission power
 * @param namespace_id namespace identifier
 * @param instance_id instance identifier
 * 
 * @return the size of the frame in bytes
 */
 
/**
 * Defines the data of an Eddystone UID frame.
 */
unsigned int setup_eddystone_UID_frame(uint8_t data[EDDYSTONE_UID_DATA_SIZE], 
    int8_t txpwr, const uint8_t namespace_id[10], const uint8_t instance_id[6])
{
    unsigned int offset = 0;
    
    data[offset] = eddystone_frame_type_uid;
    offset++;
    
    data[offset] = txpwr;
    offset++;
    
    for (unsigned int i = 0; i < 10; i++) {
        data[offset] = namespace_id[i];
        offset++;
    }
    
    for (unsigned int i = 0; i < 6; i++) {
        data[offset] = instance_id[i];
        offset++;
    }
    
    data[offset] = 0x00;
    offset++;
    data[offset] = 0x00;
    offset++;
    
    return offset;
}
  
/**
 * This function is used by BLE library to signal failed assertions.
 */
void __ble_assert(const char *file, uint16_t line)
{
    while (true);
}

/**
 * ISR for RDYN low events
 */
void rdyn_isr()
{
    // This is a level interrupt that would fire again while the
    // signal is low. Thus, we need to detach the interrupt.
    detachInterrupt(RDYN_INTR_NO);
    ble_ready = true;  
}

/**
 * Watch dog interrupt. Will be fired every second.
 * 
 * The watch dog will keep runing even in power-down mode.
 * When it fires, it will wake-up the Arduino.
 */
ISR(WDT_vect)
{  
    timer_fired = true;
}

/**
 * Setup watch dog to trigger interrupts every 1 s.
 */
void start_watchdog()
{
    // WDTCSR: Watch Dog Control Status Register
    // WDIE: Watchdog Interrupt Enable
    // WDCE: Watchdog Change Enabled
    // WDE: Watchdog System Reset Enabled
    // WDRF: Watchdog Reset Flag
    /* Watch Dog Prescaler (WDP3-0)
    0         0      0        0             2K (2048) cycles      16 ms
    0         0      0        1             4K (4096) cycles      32 ms
    0         0      1        0             8K (8192) cycles      64 ms
    0         0      1        1            16K (16384) cycles     0.125 s
    0         1      0        0            32K (32768) cycles     0.25 s
    0         1      0        1            64K (65536) cycles     0.5 s
    0         1      1        0            128K (131072) cycles   1.0 s
    0         1      1        1            256K (262144) cycles   2.0 s
    1         0      0        0            512K (524288) cycles   4.0 s
    1         0      0        1            1024K (1048576) cycles 8.0 s
    */
    // Clear WDRF or it will overwrite cleared WDE.
    MCUSR &= ~_BV(WDRF);
    byte sreg_saved;
    sreg_saved = SREG;
    cli();
    // Watchdog modus:
    //  WDE, ~WDIE: system reset mode
    // ~WDE,  WDIE: interrupt mode
    //  WDE,  WDIE: interrupt mode; after first interrupt go to system reset mode 
    // Changing timing and clearing WDE require a timed sequence:
    // Set WDCE bit; then change settings within 4 clock cycles.
    WDTCSR |= _BV(WDCE) | _BV(WDE);
    // Disable watchdog reset, enable interrupt mode, interval 1 s
    WDTCSR = _BV(WDP2) | _BV(WDP1) | _BV(WDIE);
    SREG = sreg_saved;
    wdt_reset();
}
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
void loop()
{             
    if (ble_ready) {
        // Process all pending ACI events from nRF8001.
        aci_loop();
        ble_ready = false;
        // nRF8001 will cause an interrupt when more events are available
        attachInterrupt(RDYN_INTR_NO, rdyn_isr, LOW);
    }

    if (timer_fired) {
        // For Eddystone TLM frames, we need the number of sent
        // frames since (re-)boot. nRF8001 does not tell us when 
        // it sends an advertisement. However, knowing the advertisment
        // interval and watch dog timer interval, we can estimate the 
        // number of transmitted frames. For 1 s avd. interval and 1 s
        // watch dog timer, we simply have to increase the avd. counter
        // with every timer event.
        adv_pdu_cnt++;

        // Eddystone TLM frames contain the uptime. Although other timers 
        // are stopped in power-down mode, the watch dog timer keeps running. 
        // The watch dog fires every second. Eddystone wants the uptime in
        // tens of seconds.
        uptime += 10;

        // Switch to next frame type
        set_next_frame();

        timer_fired = false;
    }

    #ifdef DO_SLEEP
    do_sleep();
    #endif
}

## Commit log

2015-08-27 Initial check-in
    [faros-328P-nrf8001-50x70.brd, faros-328P-nrf8001-50x70.sch]
2015-08-28 Added PDF of schematic.
    [faros-328P-nrf8001-50x70.sch]
2015-08-28 Increased min. restring sizes and improved clearance
    [faros-328P-nrf8001-50x70.brd]
2015-08-29 Added 50x50 double-sided layout for PCB manufacturer
    [faros-328P-nrf8001-50x50.brd, faros-328P-nrf8001-50x50.sch]
2015-08-30 Cleaned up part names. Added BOM to readme. Added PDF showing part placement for single-sided board. Updated Gerber files and PCB layout (PDF).
    [faros-328P-nrf8001-50x50.brd, faros-328P-nrf8001-50x50.sch, faros-328P-nrf8001-50x70.brd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]
2015-08-30 Added gerber files
    [faros-328P-nrf8001-50x50.GBL, faros-328P-nrf8001-50x50.GBO, faros-328P-nrf8001-50x50.GBP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]
2015-08-30 Added wires in parts-and-places PDF
2015-10-03 Added definitions at beginning of sketch to make selection of board easy
2015-10-03 Moved clock divider into board specific sections
